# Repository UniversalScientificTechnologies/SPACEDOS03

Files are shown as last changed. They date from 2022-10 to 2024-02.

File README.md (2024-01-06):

# SPACEDOS03 - semiconductor-based ionizing radiation spectrometer



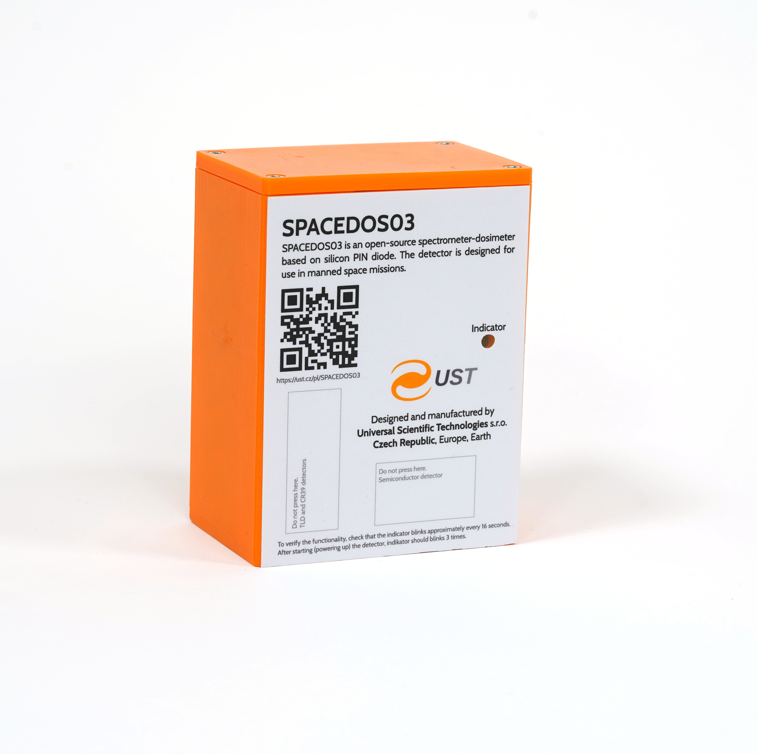
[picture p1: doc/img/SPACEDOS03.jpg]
SPACEDOS03A front panel


SPACEDOS03 is an open-source semiconductor particle detector (dosimeter and spectrometer) for space applications. The detector is based on a silicon PIN diode. The Detector is designed as autonomous for long-term measurement campaigns and therefore contains its power source from high-capacity battery cells and a recording medium in the form of an industrial SD card. The device is designed to be able to work for half a year continuously.

The detector is mounted into a 3D-printed box that contains positions for passive TLDs and track detectors. The main purpose of the device is experimental testing of radiation shielding materials in the real environment. 

## Parameters

 * Silicon PIN diode detector with 44 mm³ detection volume
 * Effective number of energy channels 470 ±3
 * Deposited energy ranges from 60 keV to 7 MeV
 * Energy measurement resolution 15 ±2 keV (depending on calibration method and type of particles)
 * Power supply 18650 Li-ion cells
 * Integration time depends on firmware setup 
 * Data storage device: Industrial SLC SDcard
 * Dimensions - 120 x 90 x 62 mm
 * Weight - 447 grams (with SAFT batteries)

* [Power module](https://github.com/ust-modules/UST5BATT18650V01)

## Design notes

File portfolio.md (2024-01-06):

---
title: "Radiation shielding materials tester"
excerpt: "SPACEDOS03 is a experimental dosimeter for testing of radiation shielding materials on board of manned spacecraft."
header:
  image: products/SPACEDOS03/doc/img/SPACEDOS03.jpg
  teaser: products/SPACEDOS03/doc/img/SPACEDOS03.jpg
  overlay_color: "#000"
  overlay_filter: "0.5"
  overlay_image: products/SPACEDOS02A/doc/src/img/SPACEDOS02A_bottom.jpg
---

SPACEDOS03A front panel

SPACEDOS03 is an open-source semiconductor particle detector (dosimeter and spectrometer) for space applications. The detector is based on a silicon PIN diode. The Detector is designed as autonomous for long-term measurement campaigns and therefore contains its own power source from high-capacity battery cells and a recording medium in the form of an industrial SD card. The device is designed to be able to work for half a year continuously.

The detector is mounted into a 3D-printed box that contains positions for passive TLDs and track detectors.

## Parameters

 * Silicon PIN diode detector with 44 mm³ detection volume
 * Effective number of energy channels 470 ±3
 * Deposited energy ranges from 60 keV to 7 MeV
 * Energy measurement resolution 15 ±2 keV (depending on calibration method and type of particles)
 * Power supply 18650 Li-ion cells
 * Integration time depends on firmware setup
 * Data storage device: Industrial SLC SDcard
 * Dimensions - 120 x 90 x 62 mm
 * Weight - 447 grams (with SAFT batteries)

The device is being used onboard ISS.

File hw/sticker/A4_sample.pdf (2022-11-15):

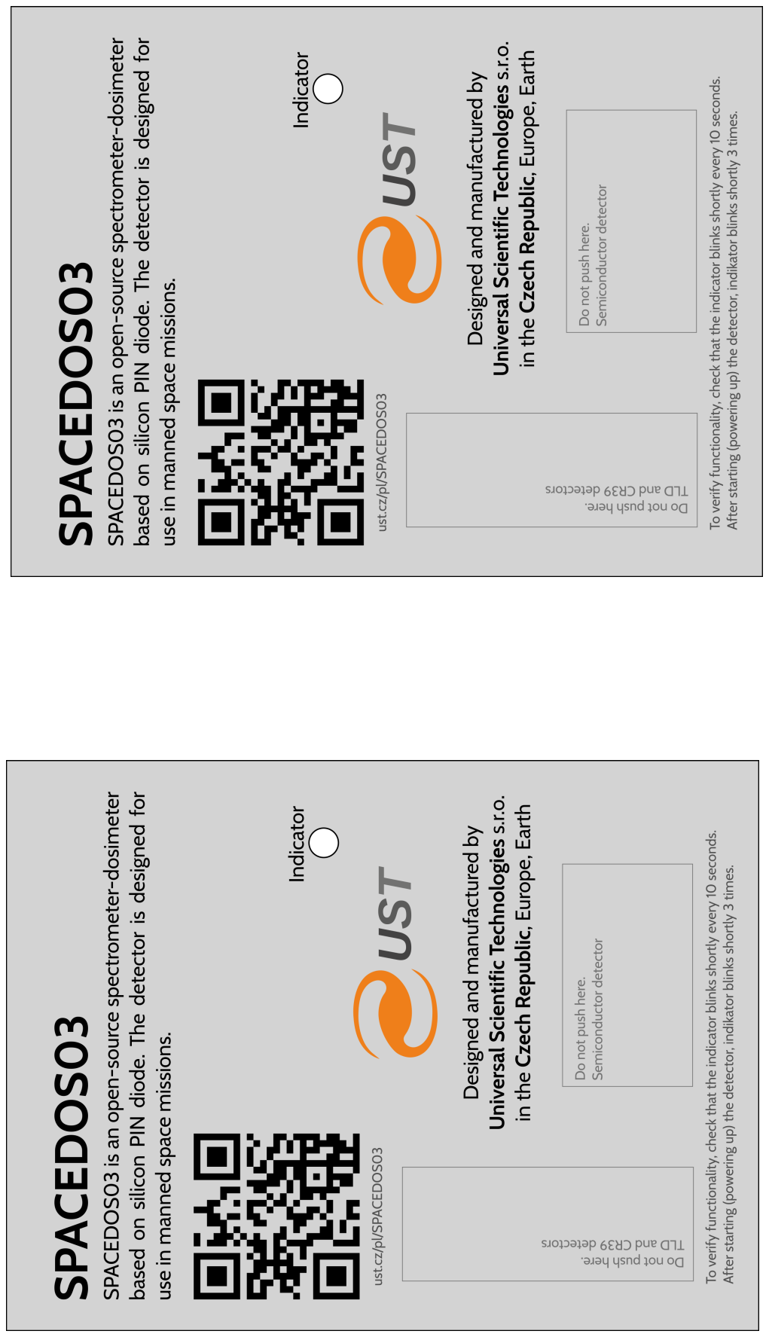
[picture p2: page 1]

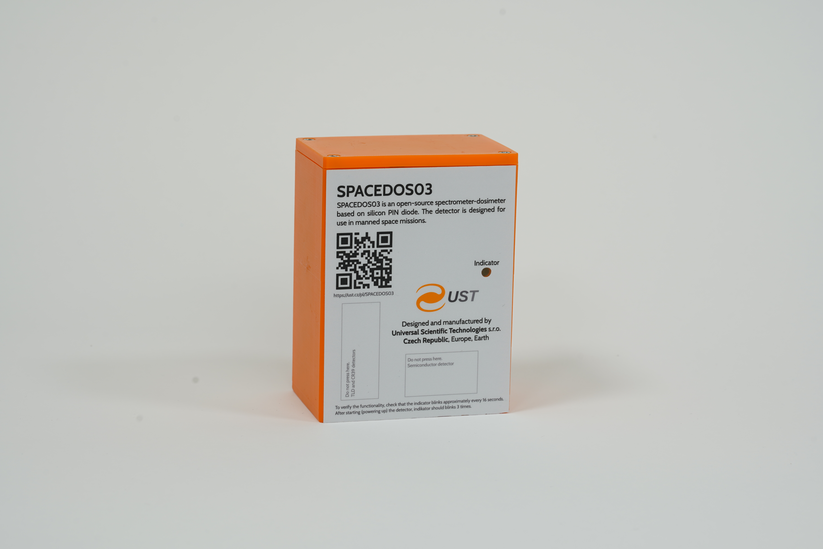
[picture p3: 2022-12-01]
doc/img/SPACEDOS03_front.jpg

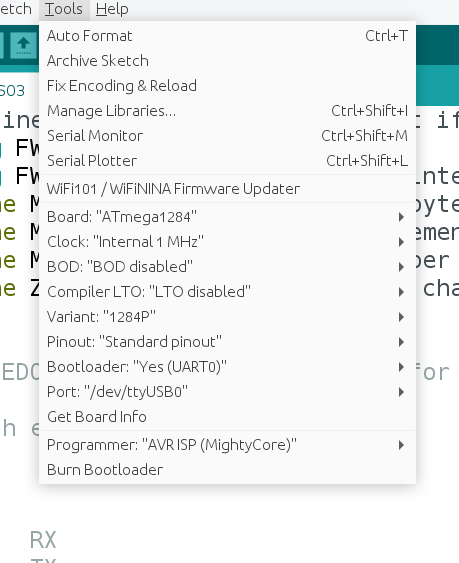
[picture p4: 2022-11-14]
fw/SPACEDOS03/compile_config.png

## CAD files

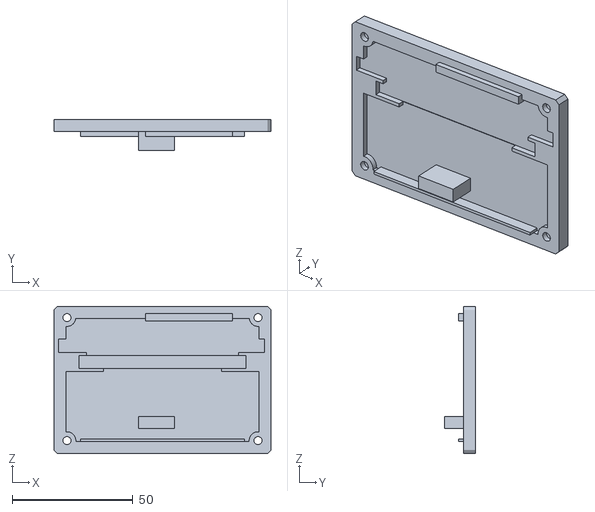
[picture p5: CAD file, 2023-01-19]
hw/stl/spacedos_cap.stl
90.0 x 12.7 x 61.0

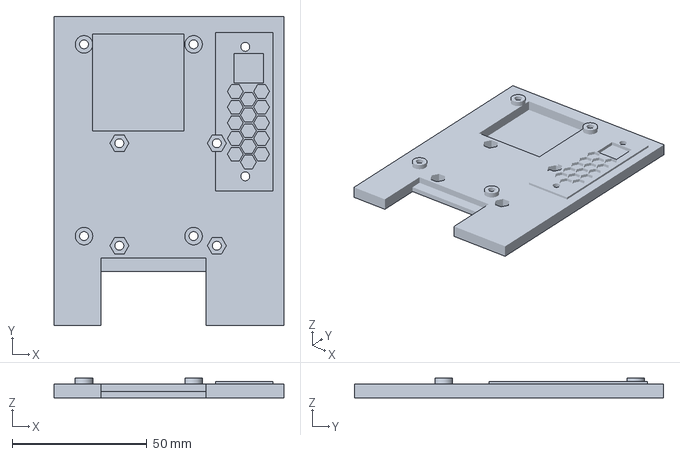
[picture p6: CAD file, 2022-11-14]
hw/stl/spacedos_desk.3mf
85.2 x 114.6 x 7.30 mm

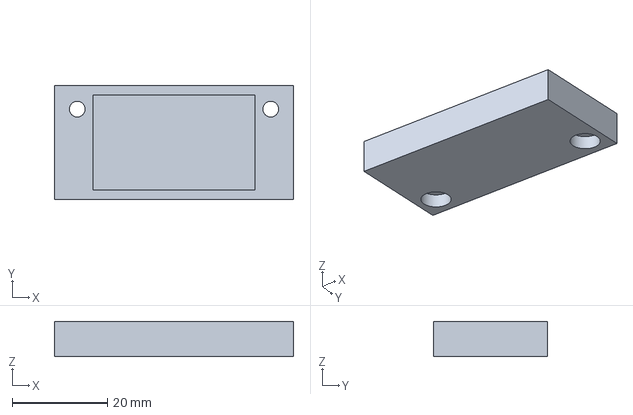
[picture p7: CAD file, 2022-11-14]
hw/stl/shield_pin.3mf
50.2 x 24.0 x 7.40 mm

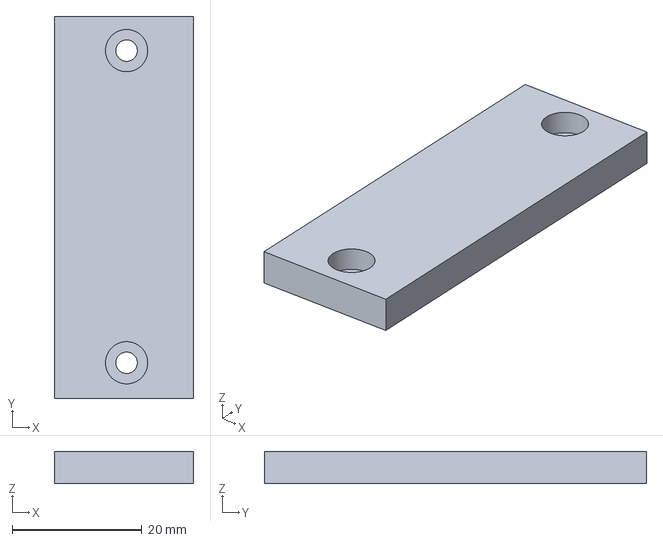
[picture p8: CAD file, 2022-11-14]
hw/stl/shield_tld.3mf
21.4 x 58.8 x 5.00 mm

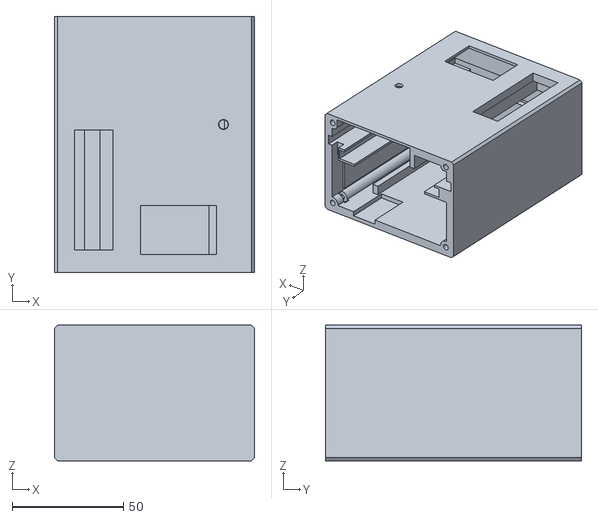
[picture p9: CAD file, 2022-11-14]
hw/stl/spacedos_box.stl
90.0 x 115.0 x 61.0

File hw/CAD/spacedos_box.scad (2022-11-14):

$fn=6;

repair=100;
repair_s=2;

toleration=0.4;// if zmena -> zmenit i u desky
//krabicka
thickness=5;

box_out_x=90;
box_out_y=120;
box_out_z=61;

box_in_x=box_out_x-2*thickness;
box_in_y=box_out_y-2*thickness;
box_in_z=box_out_z-2*thickness;

//nut
box_nut_d=6.78;
box_nut_h=3.3;
box_nut_d_x=-box_nut_d/2+box_out_x-2;
box_nut_d_x_2=box_nut_d/2+2;
box_nut_d_y=box_in_y;
box_nut_d_z=box_nut_d/2+2;
box_nut_d_z_2=box_nut_d/2+2+box_in_z;

box_nut_in_d=3.3;
box_nut_in_h=repair;
box_nut_in_repair=5;

box_nut_screw_d=6;
box_nut_screw_zapusteni=3;


//insertion
box_cor=thickness-2;
box_cor_d_xy=thickness-box_cor;
box_cor_d_z=box_cor_d_xy+36+4;
desk_z=5-1.5;//z ust_desk

//edge
edge_x=thickness-3;
edge_y=box_out_y+repair;
edge_z=repair;

//battery
bat_x=70;
bat_y=box_in_y-15;
bat_z=2+repair_s;

bat_x_trans=box_out_x/2-bat_x/2;
bat_y_trans=thickness-bat_y+box_in_y;
bat_z_trans=thickness-1.5;
/*
battery_d=33.5;
battery_h=80+(box_in_y-80)/2;//64.15
battery_in_h=32.12;
battery_distance=38/2;//19.17;
battery_zapusteni=1.5;
*/


//horni vyrez
h_v_x=46+5;
h_v_y=box_in_y;
h_v_z=1.45+2+repair_s;

h_v_x_trans=30.5;
h_v_y_trans=thickness;
h_v_z_trans=box_out_z-(thickness+repair_s);

//vystuha horni
v_h_x=3;
v_h_y=box_in_y;
v_h_z=box_in_z-box_cor_d_z+h_v_z-repair_s;

v_h_x_trans=h_v_x_trans-v_h_x;
v_h_y_trans=thickness;
v_h_z_trans=box_cor_d_z+desk_z+repair_s;

//vystuha bocni
v_b_x=box_in_x+repair_s;
v_b_y=box_in_y+repair_s;
v_b_z=v_h_x;

v_b_x_trans=-v_b_x/2+box_out_x/2;
v_b_y_trans=thickness-repair_s;
v_b_z_trans=box_out_z/3;

//vyrez vystuhy bocni
v_v_b_x=72;
v_v_b_y=box_in_y;
v_v_b_z=v_h_x+6;

v_v_b_x_trans=-v_v_b_x/2+box_out_x/2;
v_v_b_y_trans=thickness;
v_v_b_z_trans=box_out_z/3-6/2;

//vulcan
vulcan_diameter_1_out=7;
vulcan_diameter_2_out=8.5;

vulcan_diameter_1_in=3;
vulcan_diameter_2_in=4.5;
vulcan_height=1.5+thickness;

vulcan_trans_x=76;
vulcan_trans_y=thickness-box_cor+64.5;
vulcan_trans_z=box_cor_d_z+desk_z+repair_s+7;

//vnitrni opora
tloustka=1;
zapusteni=2;

//vnitrni horni opora vicka
v_o_v_x=36;
v_o_v_y=zapusteni+box_cor_d_xy;
v_o_v_z=tloustka+2;

v_o_v_x_trans=-v_o_v_x/2+h_v_x_trans+h_v_x/2;
v_o_v_y_trans=box_out_y-box_cor-v_o_v_y;
v_o_v_z_trans=box_out_z-thickness-tloustka;

//bocni vnitrni opora vicka +x
b_o_x_x=tloustka;
b_o_x_y=zapusteni+box_cor_d_xy;
b_o_x_z=10;

b_o_x_x_trans=thickness+box_in_x-b_o_x_x;
b_o_x_y_trans=box_out_y-box_cor-b_o_x_y;
b_o_x_z_trans=-b_o_x_z+box_cor_d_z;

//bocni vnitrni opora vicka -x
b_o__x_x=tloustka;
b_o__x_y=zapusteni+box_cor_d_xy;
b_o__x_z=10;

b_o__x_x_trans=thickness;
b_o__x_y_trans=box_out_y-box_cor-b_o_x_y;
b_o__x_z_trans=-b_o_x_z+box_cor_d_z;

//vnitrni dolni opora vicka
v_d_v_x=bat_x-repair_s;
v_d_v_y=zapusteni+box_cor_d_xy;
v_d_v_z=tloustka;

v_d_v_x_trans=-v_d_v_x/2+box_out_x/2;
v_d_v_y_trans=box_out_y-box_cor-v_o_v_y;
v_d_v_z_trans=thickness;

//rozmery diody
di_in_x=34;
di_in_y=22;
di_in_z=2.4;

//pomocne pro diodu z desk
nut_d=6.5;
box_cor_2=thickness-2;
k_x=26.41-box_cor_2-repair_s/2-1;
k_y=box_in_y+box_cor+repair_s-2*box_cor_2-2*repair_s;//box_in_x+2*box_cor-2*box_cor_2-2*repair_s;

k_y_trans=repair_s/2;

k_y_zkrat=(box_in_y+box_cor+repair_s-2*box_cor_2-2*repair_s)/2-nut_d+5;

k_x_trans=box_in_x+2*box_cor-3-k_x-box_cor_2-repair_s/2+3; //if zmena -> zmenit box

plate_s_x=34;//32.70
plate_x= 50.4;//box_in_x+2*box_cor;//

//kvadr pro krystaly
k_z=3-2;
k_v_z=5;//2;

//stinitko = stinici filtr (69x115x5)
stinitko_x = 69;
stinitko_y = 115;
stinitko_z = 5;

//stinitko tloustka uchyceni
stinitko_thick_z = 1.5;
stinitko_rezerva = 0.2;

//stinitko delka v uchaceni
stinitko_le_x = 10;

//baterie
baterie_x = 78.4;
baterie_y = 100.10+2.2;
baterie_z = 23.12+0.5;

//baterie spodni podlozeni
baterie_podl_distance= 55.5;
baterie_podl_x= 3.6;

//dratek
dratek=4.6;


vicko = 0; // zobrazit krabicku nebo vicko

difference(){
    cube([box_out_x, box_out_y, box_out_z]);
    difference(){
        translate([thickness, thickness, thickness]) cube([box_in_x, box_in_y+repair_s, box_in_z]);
        
        for(i=[box_nut_d_x, box_nut_d_x_2], j=[box_nut_d_z, box_nut_d_z_2])
        translate([i, 0, j]) translate([0, -box_nut_in_repair, 0])
            rotate([-90, 90,0]) cylinder(h=box_out_y+repair,d=box_nut_h+2*repair_s, $fn=100);
        
        //stinitko upevneni
        translate([thickness/2,thickness-box_cor,box_cor_d_z-stinitko_z-2*stinitko_thick_z]) cube([box_out_x, stinitko_y, stinitko_z+2*stinitko_thick_z]);
        
        //baterie
        translate([thickness/2, thickness, box_cor_d_z-stinitko_z-2*stinitko_thick_z-baterie_z]) cube([box_out_x, baterie_y, baterie_z]);
        
        //baterie spodni podlozeni
        for(i=[-baterie_podl_distance/2, baterie_podl_distance/2])translate([thickness+box_in_x/2-baterie_podl_x/2+i,thickness,0]) cube([baterie_podl_x,87,10+thickness]);
            
    
        }
   
    //insertion
    translate([box_cor_d_xy-toleration/2, box_cor_d_xy, box_cor_d_z])cube([box_in_x+2*box_cor-toleration, box_in_y+box_cor+repair_s, desk_z+repair_s]);
    
    //stinitko
    translate([-stinitko_x/2+box_out_x/2-stinitko_rezerva,thickness-box_cor-stinitko_rezerva,box_cor_d_z-stinitko_z-stinitko_thick_z-stinitko_rezerva]) cube([stinitko_x+2*stinitko_rezerva, stinitko_y+2*stinitko_rezerva, stinitko_z+2*stinitko_rezerva]);
    
    //stinitko zbaveni desek okolo
    translate([(-stinitko_x+2*stinitko_le_x+box_out_x)/2, thickness-box_cor,box_cor_d_z-stinitko_z-2*stinitko_thick_z])cube([stinitko_x-2*stinitko_le_x, stinitko_y, stinitko_z+2*(stinitko_thick_z)]);
     
    translate([(-stinitko_x+2*(stinitko_le_x-7)+box_out_x)/2, thickness-box_cor,box_cor_d_z-stinitko_z-2*stinitko_thick_z+stinitko_thick_z])cube([stinitko_x-2*(stinitko_le_x-7), stinitko_y, stinitko_z+2*(stinitko_thick_z)]);
    
//baterie
    translate([(-baterie_x+box_out_x)/2, thickness, box_cor_d_z-stinitko_z-2*stinitko_thick_z-baterie_z]) cube([baterie_x, baterie_y, baterie_z]);
    
    translate([55, 90, box_cor_d_z-stinitko_z-2*stinitko_thick_z-baterie_z-8]) cube([15, 25, 15]);
    
    //translate([thickness,thickness, box_cor_d_z-stinitko_z-2*stinitko_thick_z-baterie_z/2-baterie_z/4]) cube([box_in_x, baterie_y, baterie_z/2]);
        
    //dratek
        translate([box_out_x-thickness-dratek, box_out_y-thickness-dratek,box_cor_d_z-stinitko_z-2*stinitko_thick_z]) cube([dratek, dratek, stinitko_z+2*stinitko_thick_z]);    
        
    //screw
    for(i=[box_nut_d_x, box_nut_d_x_2], j=[box_nut_d_z, box_nut_d_z_2]){
        translate([i, box_nut_d_y, j]) 
            union(){
                translate([0, -box_nut_in_repair, 0]) rotate([-90, 90, 0])cylinder(h=box_nut_in_h, d=box_nut_in_d, $fn=100);
               translate([0, 2*thickness,0]) rotate([90,0,0]) cylinder(h=box_nut_screw_zapusteni, d=box_nut_screw_d, $fn=100);
            }
        }
        
     //nut
     hull(){
            translate([box_nut_d_x, box_nut_d_y, box_nut_d_z_2]) rotate([90, 30,0]) cylinder(h=box_nut_h, d=box_nut_d);
            translate([box_nut_d_x_2, box_nut_d_y, box_nut_d_z]) rotate([90, 30,0]) cylinder(h=box_nut_h, d=box_nut_d);      
      }
      
      hull(){
            translate([box_nut_d_x, box_nut_d_y, box_nut_d_z]) rotate([90, 30,0]) cylinder(h=box_nut_h, d=box_nut_d);
            translate([box_nut_d_x_2, box_nut_d_y, box_nut_d_z_2]) rotate([90, 30,0]) cylinder(h=box_nut_h, d=box_nut_d);      
      }
  
    //edge i,j,k
        translate([box_out_x/2,0, box_out_z/2]) for(i=[0:3]) rotate([0,i*90,0])
        translate([box_out_x/2,edge_y/2-repair_s,box_out_z/2]) rotate([0,-45,0]) cube([edge_x, edge_y, edge_z], center=true);  
      
    //cover
    if(vicko){
    translate([-repair_s,box_out_y-thickness,-repair_s]) cube([box_out_x+repair, thickness+repair, box_out_z+repair]);
    }else{
        translate([-repair_s,-thickness,-repair_s]) cube([box_out_x+repair, box_out_y, box_out_z+repair]);

    }
    
    
    
        
    
    //vulcan odecet
    translate([vulcan_trans_x, vulcan_trans_y, vulcan_trans_z]) cylinder(h=vulcan_height, d1=vulcan_diameter_1_in, d2=vulcan_diameter_2_in, $fn=100);
    
    //battery
    //translate([bat_x_trans, bat_y_trans, bat_z_trans]) cube([bat_x, bat_y, bat_z]);
 
    
    //vyrez pro diodu
    translate([(h_v_x_trans+h_v_x)/2-2,box_cor+repair_s+3,box_in_z+thickness])
        cube([di_in_x, di_in_y, di_in_z+2*repair_s]);
    //puvodni trans_x: box_out_x-0.3-(plate_x-plate_s_x)/2)-di_in_x

    //vyrez pro zasunuti krabicky na krystaly
   
    if(vicko) translate([thickness, thickness,box_cor_d_z+desk_z+repair_s]) cube([k_x,k_y+repair,k_z+k_v_z]);
    
    //vyrez pro krabicku na TLD
    translate([thickness+4,thickness+5,box_cor_d_z+desk_z+repair_s])cube([k_x-4, k_y-k_y_zkrat, k_z+k_v_z+repair]);

    //horni vyrez
    translate([h_v_x_trans,h_v_y_trans,h_v_z_trans]) cube([h_v_x, h_v_y, h_v_z]);
}  

if(vicko){
    //vystuha horni
    translate([v_h_x_trans, v_h_y_trans, v_h_z_trans]) cube([v_h_x, v_h_y,v_h_z]);
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

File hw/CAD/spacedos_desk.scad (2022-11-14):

$fn=100;

repair=100;
repair_s=2;
toleration=0.4;// if zmena -> zmenit i u boxu
//plate_s
//potreba pro plate_s z ust_box
thickness=5;

box_out_x=90;
box_out_y=120;
box_out_z=61;

box_in_x=box_out_x-2*thickness;
box_in_y=box_out_y-2*thickness;
box_in_z=box_out_z-2*thickness;

box_cor=thickness-2-toleration;

desk_z=5-toleration-1.5;//z ust_desk
////
plate_x= 50.4;//box_in_x+2*box_cor;//
plate_y=92.27;//box_in_y+box_cor+repair_s; //92.27;
plate_z= 4.34-1.5;//desk_z+repair_s;//

//vyrez na "krabicku"
plate_s_x=34;//32.70
plate_s_y=plate_s_x+2;
plate_s_z=6.32+1.3-0.5;

plate_s_z_trans=-0.5;
plate_s_distance=2.22-2/2;
plate_s_thickness=1;

//screw
nut_d_in=3.3;
nut_d_out=6.5;
spacedos_middle_x = 25;
nut_distance_x=spacedos_middle_x - 40.64/2;//1.87+nut_d_out/2;
nut_distance_y=-7+12;
nut_distance_y_2 = nut_distance_y+71.12;
nut_distance_x_2=spacedos_middle_x + 40.64/2;
nut_height=2.2+repair_s;//(plate_s_z+plate_s_thickness)-plate_z;

//nut
nut_d=6.5;
nut_h=3-plate_s_thickness;

//cut_out
c_c_x=35+4;
c_c_y=8;
c_c_z=5;//4.24
c_c_x_trans=-4/2;
c_c_distance_x=2+c_c_x_trans;
c_c_distance_y=plate_y-c_c_y;
c_c_distance_z=plate_s_thickness;
cube_i_y=5;

//translate_all
t_all_y=14;

///////////////////////////
//desk
desk_x=71.90;
desk_y=90.85;
//desk_z=5;//zapsano driv(20)
desk_overlap=3.3;

//nut
nut_diameter=7.05;//6.95;
nut_height_1=4+repair; //3.80
nut_d_x=15.15+desk_overlap+nut_diameter/2-0.77;
nut_d_x_2=(box_in_x+2*box_cor)/2+35.5/2-3;//desk_x+2*desk_overlap-15-nut_diameter/2;
nut_d_y=26.6;//23.01+nut_diameter/2;
nut_d_y_2=26.6+38;//64.69;//desk_y-23.35-nut_diameter/2;

box_nut_in_d=3.3;
box_nut_in_h=repair;

//correction (vycnelky spodni)
cor_diameter=2.97;
cor_d_x=2.09+desk_overlap;
cor_d_x_2=desk_x+2*desk_overlap-cor_d_x;
cor_d_y=26.19;
cor_d_y_2=desk_y-cor_d_y;
cor_height=3;

box_cor_2=thickness-2;

//kvadr pro krystaly
k_x=26.41-box_cor_2-repair_s/2-1;
k_y=box_in_y+box_cor+repair_s-2*box_cor_2-2*repair_s;//box_in_x+2*box_cor-2*box_cor_2-2*repair_s;
k_z=3-2;
k_y_zkrat=(box_in_y+box_cor+repair_s-2*box_cor_2-2*repair_s)/2-nut_d;

k_x_trans=box_in_x+2*box_cor-3-k_x-box_cor_2-repair_s/2+3; //if zmena -> zmenit box
k_y_trans=repair_s/2;
k_z_trans=desk_z+repair_s+(-desk_z-repair_s+plate_z+repair_s);

//kvadr pro krystaly vicko (x,y jako u kvadr pro krystaly)
k_v_z=5;//2;

//otvory pro krystaly
o_k_height=0.8+0.5;
o_k_diameter=4.7+0.75+((4.7+0.75)/2)*0.15425144988;
echo("prumer chlivecku, k opsana", o_k_diameter);
///////////////?
o_k_x_trans=k_x_trans+o_k_diameter;
o_k_y_trans=k_y_trans+k_y/2+((k_y-20)/4)/4;
o_k_z_trans=k_z+k_z_trans-o_k_height;

o_k_x_trans_posun=k_x;
o_k_y_trans_posun=(k_y-20)/8;
   
//koeficient pro posunuta vzdalenosti der pro krystaly
koeficient = 1.1;

//otvory pro krystaly 2.rada
o_k_x_2_trans=k_x_trans-o_k_diameter/2+k_x/2;//k_x_trans+k_x-2*o_k_diameter;
o_k_y_2_trans=k_y_trans+k_y/2;

//nut kvadr pro krystaly
nut_zapusteni=3+repair_s;
nut_zapusteni_trans_z=0;

//otvor pro krystal - cube
o_k_c=11;
o_k_c_height=1.5;

vicko=0;
//krystaly=1;
//tld_box = 1;

//plate
difference(){
    translate([-3,0,0]) union(){
       
        
        //vlozena deska
        //cube([plate_x, plate_y,plate_z+repair_s]);
       
        //velka deska
        translate([0,-3,-desk_z-repair_s+plate_z+repair_s])cube([box_in_x+2*box_cor, box_in_y+box_cor+repair_s, desk_z+repair_s]);
        
        //kvadr pro krystaly
        translate([k_x_trans, k_y_trans+k_y_zkrat, k_z_trans])
            cube([k_x, k_y-k_y_zkrat, k_z]);
        echo([k_x, k_y-k_y_zkrat, k_z]);
        
        
        //kvadr pro krystaly vicko
        translate([k_x_trans, k_y_trans+k_y_zkrat, k_z_trans+k_z+0.5]) cube([k_x, k_y-k_y_zkrat, k_v_z]);

       if(!vicko)
        //nuts_horni, $fn=100
        translate([plate_x+box_cor_2+3, plate_y+t_all_y, 0])rotate([0,0,180])
        for(i=[nut_distance_x, nut_distance_x_2], j=[nut_distance_y, nut_distance_y_2]){
        translate([i,j,plate_z]){
        difference(){
            cylinder(h=nut_height,d=nut_d_out);
            translate([0,0,-repair_s])cylinder(h=nut_height+repair,d=nut_d_in);
        }           
    }
}



        }
    
    
    translate([plate_x+box_cor_2, plate_y+t_all_y, plate_s_thickness])rotate([0,0,180]){
        
        //vyrez na "krabicku"
        translate([(plate_x-plate_s_x)/2, plate_s_distance, plate_s_z_trans]) cube([plate_s_x, plate_s_y, plate_s_z]);
       
       //vyrezy na konektory
        translate([c_c_distance_x, c_c_distance_y, c_c_distance_z]){            cube([c_c_x,c_c_y+repair,c_c_z+repair]);
        translate([0,cube_i_y,-desk_z-repair_s])
            cube([c_c_x,c_c_y+repair,c_c_z+repair]);
    }
   //nut_horni, $fn=6 + dira
    for(i=[nut_distance_x, nut_distance_x_2], j=[nut_distance_y, nut_distance_y_2]){
        translate([i,j,plate_z]){ translate([0,0,-plate_z-repair_s]) rotate([0,0,30]) cylinder(h=nut_h+repair_s, d=nut_d, $fn=6);
        translate([0,0,-4*repair_s])cylinder(h=nut_height+repair,d=nut_d_in);
        }
        }
    }
   translate([0,0,0]){ 
    //nut_spodni
    if(0){
       #for(i=[nut_d_x, nut_d_x_2 ], j=[nut_d_y, nut_d_y_2]){
        translate([i ,j, 1]) union(){
            cylinder(h=nut_height_1, d=nut_diameter, $fn=6);
            translate([0,0,-repair/2]) cylinder(h=box_nut_in_h, d=box_nut_in_d);
            }
        }
    }
        
    //vycnelky_spodni
    if(0) for(i=[cor_d_x, cor_d_x_2], j=[cor_d_y, cor_d_y_2]){
        translate([i, j, -repair_s])cylinder(h=cor_height, d=cor_diameter);
        }       
    }    
    
    translate([-5, -5, -5]) cube(10);
    
    translate([-1.5, 0, 0]){
    //otvor pro krystal - cube
    translate([2+o_k_x_2_trans-o_k_diameter,o_k_y_2_trans-o_k_diameter/2+6.3*o_k_diameter-0.4,o_k_z_trans+o_k_height-o_k_c_height])cube([o_k_c, o_k_c, o_k_c_height]);
    
    translate([1+0.5,k_y/5-0.4*o_k_diameter+0.3,0]){
     //otvory pro krystaly 1.rada
    for(i=[(-1/2*(o_k_y_trans_posun))*koeficient, 1/2 * (o_k_y_trans_posun)*koeficient, -(o_k_y_trans_posun)*koeficient, 0*(o_k_y_trans_posun*koeficient), o_k_y_trans_posun*koeficient]){
        translate([0,i,0]) translate([-o_k_diameter+o_k_x_2_trans+1, o_k_y_2_trans, o_k_z_trans]) cylinder(h=o_k_height, d=o_k_diameter, $fn=6);
    }
    
    //otvory pro krystaly 2.rada
    for(i=[(-1/2*(o_k_y_trans_posun))*koeficient, 1/2 * (o_k_y_trans_posun)*koeficient, -(o_k_y_trans_posun)*koeficient, 0*(o_k_y_trans_posun)*koeficient, o_k_y_trans_posun*koeficient]){
        translate([0,i,0]) translate([o_k_x_2_trans, o_k_y_2_trans-o_k_diameter/2, o_k_z_trans]) cylinder(h=o_k_height, d=o_k_diameter, $fn=6);
    }
     //otvory pro krystaly 3.rada
    for(i=[(-1/2*(o_k_y_trans_posun))*koeficient, 1/2 * (o_k_y_trans_posun)*koeficient, -(o_k_y_trans_posun)*koeficient, 0*(o_k_y_trans_posun)*koeficient, o_k_y_trans_posun*koeficient]){
        translate([0,i,0]) translate([o_k_diameter+o_k_x_2_trans-1, o_k_y_2_trans, o_k_z_trans]) cylinder(h=o_k_height, d=o_k_diameter, $fn=6);
    }
    
    }
}
    

    //nut kvadr pro krystaly    
    for(i=[nut_d+k_y_zkrat, k_y-nut_d/2-2.3]){
        echo("poloha sroubu", i);
        translate([k_x_trans+k_x/2-box_cor, i+0.8, -repair_s/7]){
    translate([0,0,0]) rotate([0,0,30]) cylinder(h=nut_h+repair_s, d=nut_d, $fn=6);
        translate([0,0,-4*repair_s])cylinder(h=nut_height+repair,d=nut_d_in);
        translate([0,0,k_z_trans+k_z+repair_s/7+repair_s]) cylinder(h=nut_zapusteni, d=nut_d, $fn=100);
        }
    }
    
       
   if(vicko){
    translate([-repair/2,-repair/2,-desk_z-repair+desk_z+repair_s+k_z]) cube([desk_x+repair, desk_y+repair, desk_z+repair]);
   }else{
        translate([k_x_trans-repair_s*4+1, k_y_trans+k_y_zkrat-1, k_z_trans+k_z]) cube([desk_x+repair, desk_y+repair, desk_z+repair]);
   }
}

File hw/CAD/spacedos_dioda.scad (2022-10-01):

$fn=100;

repair_s=2;
repair=100;

//sirka sroubu 
vzdalenost_sroubu=4*10.16; //jejich stredu

//rozmery diody
di_in_x=34;
di_in_y=20;
di_in_z=2.4;

//stinitko diody
di_out_x=50.2;
di_out_y=24;
di_out_z=di_in_z+5;

nut_d_y_2=26.6+38;
thickness=5;

box_out_y=120;
box_in_y=box_out_y-2*thickness;


//nut
nut_height=2.2+repair_s;//(plate_s_z+plate_s_thickness)-plate_z;
nut_d_in=3.3;
nut_d=6.5;


nut_trans_y=di_out_y/2-5;

nut_zapusteni=3+repair_s;


difference(){
    cube([di_out_x, di_out_y, di_out_z], center=true);
    #translate([0,0,-di_out_z/2+(di_in_z)/2]) cube([di_in_x, di_in_y, di_in_z], center =true);
    
   for(i=[vzdalenost_sroubu/2, -vzdalenost_sroubu/2]){ translate([i,nut_trans_y,-di_out_z-repair_s])cylinder(h=nut_height+repair,d=nut_d_in);
    translate([i,nut_trans_y,di_out_z/2-nut_zapusteni+repair_s]) cylinder(h=nut_zapusteni, d=nut_d, $fn=100);
    }
    
    
}

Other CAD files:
hw/stl/shield_pin.stl
hw/stl/shield_tld.stl
hw/stl/spacedos_desk.stl

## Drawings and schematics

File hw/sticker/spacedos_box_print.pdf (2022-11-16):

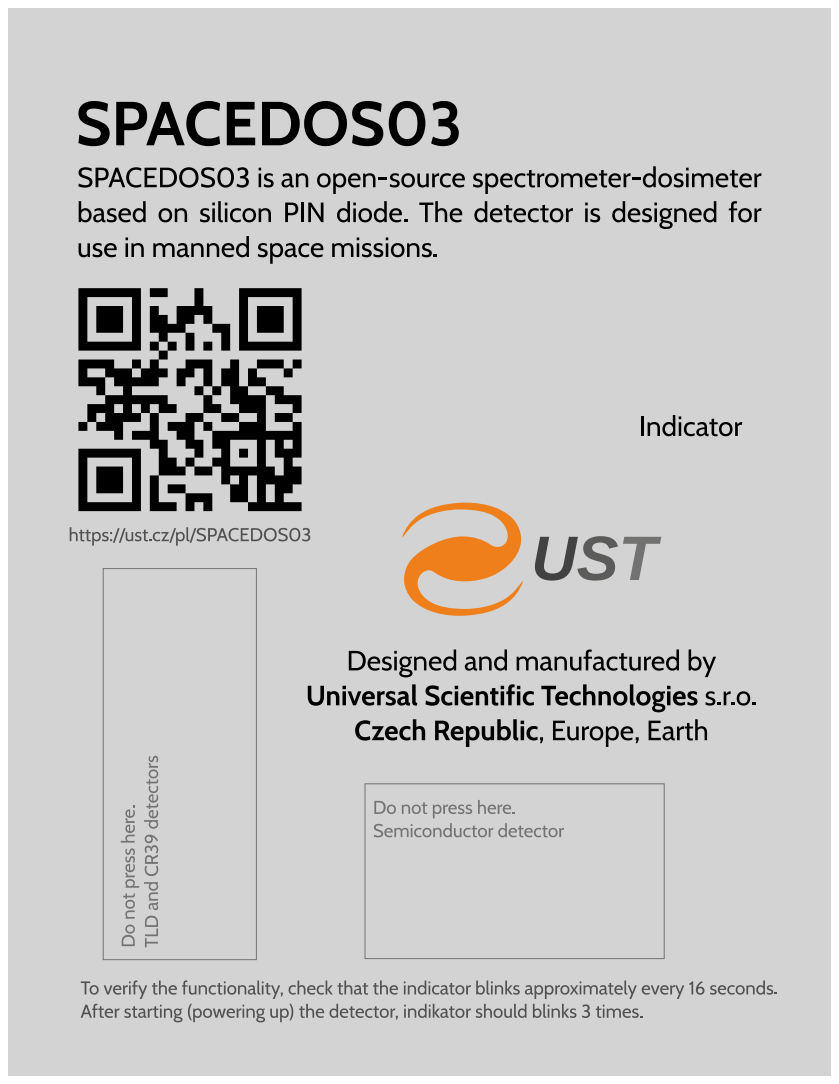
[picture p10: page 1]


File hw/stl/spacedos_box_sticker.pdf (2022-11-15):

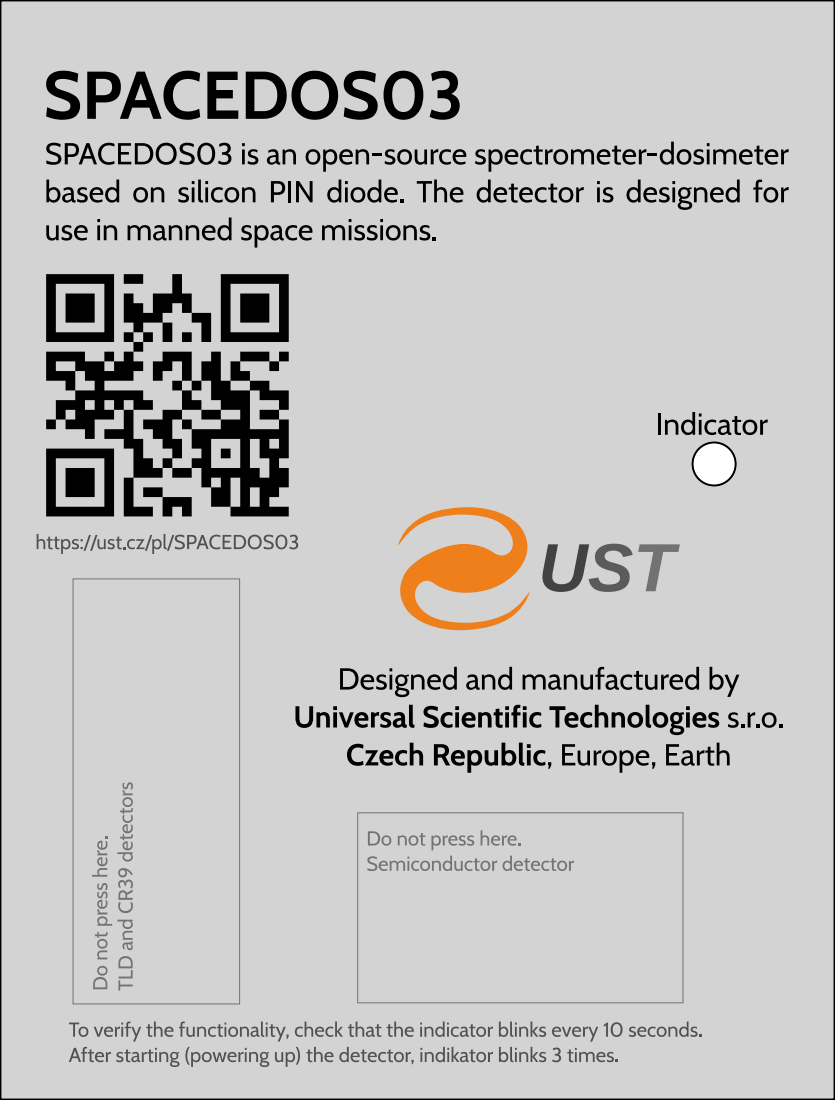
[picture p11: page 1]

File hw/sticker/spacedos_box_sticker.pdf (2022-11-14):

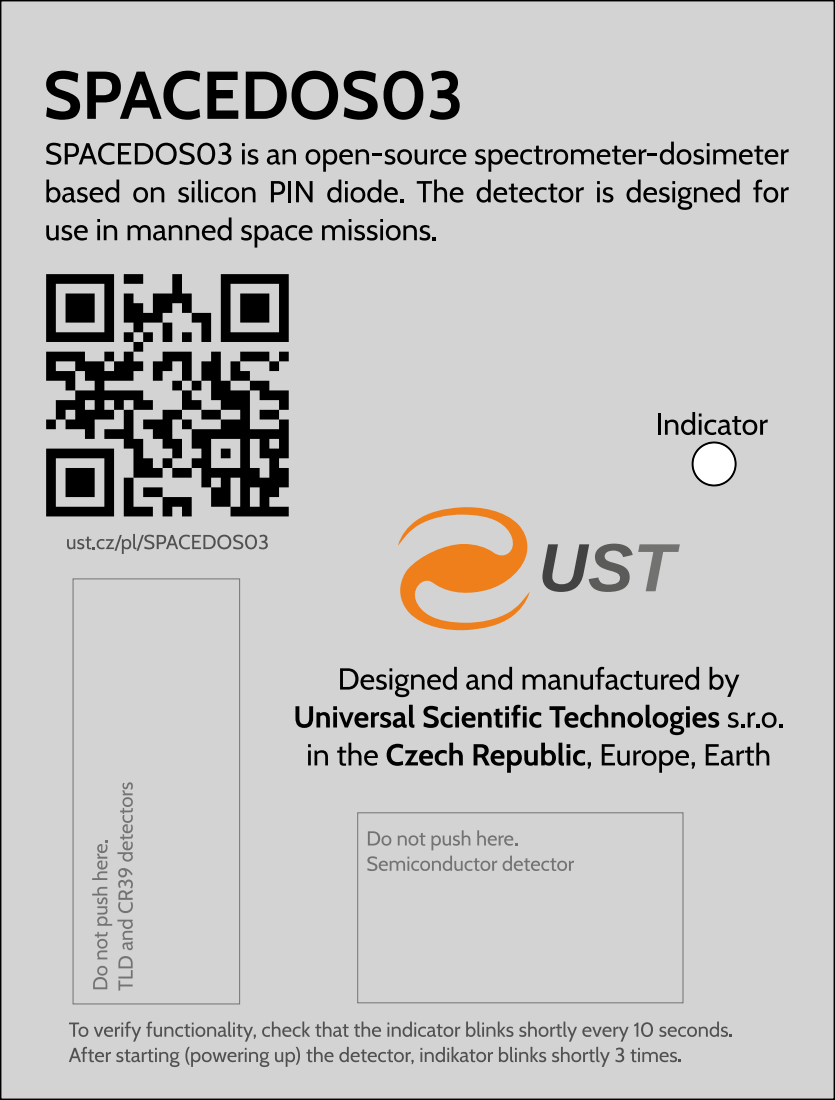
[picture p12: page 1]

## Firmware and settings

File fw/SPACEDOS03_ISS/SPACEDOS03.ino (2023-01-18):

//#define DEBUG // Please comment it if you are not debugging
// Compiled with: Arduino 1.8.13
// MightyCore 2.0.3
String HWtype = "SPACEDOS03";
String FWversion = "S04"; // 1 MHz internal oscillator / 500 kHz during integration 
#define MAXFILESIZE MAX_MEASUREMENTS * BYTES_MEASUREMENT // in bytes, 4 MB per day, 28 MB per week, 122 MB per month
#define MAX_MEASUREMENTS 11000ul // in measurement cycles, 5 500 per day
#define BYTES_MEASUREMENT 531ul // number of bytes per one measurement
#define MAXFILES 200 // maximal number of files on SD card
#define ZERO 256  // 5th channel is channel 1 (column 10 from 0, ussually DCoffset or DCoffset+1)

/*
  SPACEDOS03 derived from AIRDOS-F for USTSIPIN02A
 
6 month endurance with 5x LG 18650
https://batterybro.com/blogs/18650-wholesale-battery-reviews/40773059-new-lg-mj1-18650-battery-review-3500mah

ISP
---
PD0     RX
PD1     TX
RESET#  through 50M capacitor to RST#

SDcard
------
DAT3   SS   4 B4
CMD    MOSI 5 B5
DAT0   MISO 6 B6
CLK    SCK  7 B7

ANALOG
------
+      A0  PA0
-      A1  PA1
RESET  0   PB0

LED
---
LED_green  23  PC7      


                     Mighty 1284p    
                      +---\/---+
           (D 0) PB0 1|        |40 PA0 (AI 0 / D24)
           (D 1) PB1 2|        |39 PA1 (AI 1 / D25)
      INT2 (D 2) PB2 3|        |38 PA2 (AI 2 / D26)
       PWM (D 3) PB3 4|        |37 PA3 (AI 3 / D27)
    PWM/SS (D 4) PB4 5|        |36 PA4 (AI 4 / D28)
      MOSI (D 5) PB5 6|        |35 PA5 (AI 5 / D29)
  PWM/MISO (D 6) PB6 7|        |34 PA6 (AI 6 / D30)
   PWM/SCK (D 7) PB7 8|        |33 PA7 (AI 7 / D31)
                 RST 9|        |32 AREF
                VCC 10|        |31 GND
                GND 11|        |30 AVCC
              XTAL2 12|        |29 PC7 (D 23)
              XTAL1 13|        |28 PC6 (D 22)
      RX0 (D 8) PD0 14|        |27 PC5 (D 21) TDI
      TX0 (D 9) PD1 15|        |26 PC4 (D 20) TDO
RX1/INT0 (D 10) PD2 16|        |25 PC3 (D 19) TMS
TX1/INT1 (D 11) PD3 17|        |24 PC2 (D 18) TCK
     PWM (D 12) PD4 18|        |23 PC1 (D 17) SDA
     PWM (D 13) PD5 19|        |22 PC0 (D 16) SCL
     PWM (D 14) PD6 20|        |21 PD7 (D 15) PWM
                      +--------+
*/

#include <SD.h>         
#include "wiring_private.h"
#include <Wire.h>   

#define LED         23   // PC7
#define RESET       0    // PB0
#define SDpower1    1    // PB1
#define SDpower2    2    // PB2
#define SDpower3    3    // PB3
#define SS          4    // PB4
#define MOSI        5    // PB5
#define MISO        6    // PB6
#define SCK         7    // PB7
#define INT         20   // PC4
#define ANALOG_ON   15   // PD7
#define LED1        21   // PC5
#define LED2        22   // PC6
#define LED3        23   // PC7

#define CHANNELS 512 // number of channels in buffer for histogram, including negative numbers

String filename = "";
uint16_t fn;
uint32_t count = 0;
uint32_t serialhash = 0;
uint16_t base_offset = ZERO - 1;
uint8_t lo, hi;
uint16_t u_sensor;

// Read Analog Differential without gain (read datashet of ATMega1280 for refference)
// Use analogReadDiff(NUM)
//   NUM  | POS PIN             | NEG PIN           |   GAIN
//  0 | A0      | A1      | 1x
//  1 | A1      | A1      | 1x
//  2 | A2      | A1      | 1x
//  3 | A3      | A1      | 1x
//  4 | A4      | A1      | 1x
//  5 | A5      | A1      | 1x
//  6 | A6      | A1      | 1x
//  7 | A7      | A1      | 1x
//  8 | A8      | A9      | 1x
//  9 | A9      | A9      | 1x
//  10  | A10     | A9      | 1x
//  11  | A11     | A9      | 1x
//  12  | A12     | A9      | 1x
//  13  | A13     | A9      | 1x
//  14  | A14     | A9      | 1x
//  15  | A15     | A9      | 1x
#define PIN 0
uint8_t analog_reference = INTERNAL2V56; // DEFAULT, INTERNAL, INTERNAL1V1, INTERNAL2V56, or EXTERNAL
// the differential channels should not be used with an AREF < 2V

uint32_t tm;

uint8_t bcdToDec(uint8_t b)
{
  return ( ((b >> 4)*10) + (b%16) );
}

void readRTC()
{
  Wire.beginTransmission(0x51);
  Wire.write(0);
  Wire.endTransmission();
  
  Wire.requestFrom(0x51, 6);
  Wire.read();
  //tm_s100 = bcdToDec(Wire.read());
  uint8_t tm_sec = bcdToDec(Wire.read() & 0x7f);
  uint8_t tm_min = bcdToDec(Wire.read() & 0x7f);
  tm = bcdToDec(Wire.read());
  tm += bcdToDec(Wire.read()) * 100;
  tm += bcdToDec(Wire.read()) * 10000;
  tm = tm * 60 * 60 + tm_min * 60 + tm_sec;
}

void(* resetFunc) (void) = 0; //declare reset function at address 0

void setup()
{
  // Open serial communications 
  enablePower(POWER_SERIAL0);
  interrupts();
  Serial.begin(9600);
  for(int i=0; i<3; i++)  
  {
    delay(300);
    digitalWrite(LED, HIGH);  // Blink indicating inserting batteryes (or reset)
    delay(10);
    digitalWrite(LED, LOW);  
  }
  Serial.println("#Cvak...");
  
  ADMUX = (analog_reference << 6) | ((PIN | 0x10) & 0x1F);
  
  ADCSRB = 0;               // Switching ADC to Free Running mode
  sbi(ADCSRA, ADATE);       // ADC autotrigger enable (mandatory for free running mode)
  sbi(ADCSRA, ADSC);        // ADC start the first conversions
  sbi(ADCSRA, 2);           // 0x100 = clock divided by 16, 62.5 kHz, 208 us for 13 cycles of one AD conversion, 24 us fo 1.5 cycle for sample-hold
  cbi(ADCSRA, 1);        
  cbi(ADCSRA, 0);        

  //pinMode(SDpower1, OUTPUT);  // SDcard interface
  //pinMode(SDpower2, OUTPUT);     
  //pinMode(SDpower3, OUTPUT);     
  //pinMode(SS, OUTPUT);     
  //pinMode(MOSI, INPUT);     
  //pinMode(MISO, INPUT);     
  //pinMode(SCK, OUTPUT);  

  DDRB = 0b10011110;
  PORTB = 0b00000000;  // SDcard Power OFF
  DDRA = 0b11111100;
  PORTA = 0b00000000;  
  DDRC = 0b11101100;
  PORTC = 0b00000000;  
  DDRD = 0b11111111;  
  PORTD = 0b10000000; // Analog Power ON 
  

  //!!! Wire.setClock(100000);
  // Initiation of RTC
  Wire.beginTransmission(0x51); // init clock
  Wire.write((uint8_t)0x23); // Start register
  Wire.write((uint8_t)0x00); // 0x23
  Wire.write((uint8_t)0x00); // 0x24 Two's complement offset value
  Wire.write((uint8_t)0b00000101); // 0x25 Normal offset correction, disable low-jitter mode, set load caps to 6 pF
  Wire.write((uint8_t)0x00); // 0x26 Battery switch reg, same as after a reset
  Wire.write((uint8_t)0x00); // 0x27 Enable CLK pin, using bits set in reg 0x28
  Wire.write((uint8_t)0x97); // 0x28 stop watch mode, no periodic interrupts, CLK pin off
  Wire.write((uint8_t)0x00); // 0x29
  Wire.write((uint8_t)0x00); // 0x2a
  Wire.endTransmission();
/*
  Wire.beginTransmission(0x51); // reset clock
  Wire.write(0x2f); 
  Wire.write(0x2c);
  Wire.endTransmission();
  Wire.beginTransmission(0x51); // start stop-watch
  Wire.write(0x28); 
  Wire.write(0x97);
  Wire.endTransmission();
  Wire.beginTransmission(0x51); // reset stop-watch
  Wire.write((uint8_t)0x00); // Start register
  Wire.write((uint8_t)0x00); // 0x00
  Wire.write((uint8_t)0x00); // 0x01 
  Wire.write((uint8_t)0x00); // 0x02 
  Wire.write((uint8_t)0x00); // 0x03
  Wire.write((uint8_t)0x00); // 0x04
  Wire.write((uint8_t)0x00); // 0x05
  Wire.endTransmission();
*/

  {
    // measurement of ADC offset
    ADMUX = (analog_reference << 6) | 0b10001; // Select +A1,-A1 for offset correction
    ADCSRB = 0;               // Switching ADC to Free Running mode
    sbi(ADCSRA, ADATE);       // ADC autotrigger enable (mandatory for free running mode)
    sbi(ADCSRA, ADSC);        // ADC start the first conversions
    sbi(ADCSRA, 2);           // 0x100 = clock 1 MHz divided by 16, 62.5 kHz, 208 us for 13 cycles of one AD conversion, 24 us fo 1.5 cycle for sample-hold
    cbi(ADCSRA, 1);
    cbi(ADCSRA, 0);
    sbi(ADCSRA, ADIF);                  // reset interrupt flag from ADC
    while (bit_is_clear(ADCSRA, ADIF)); // wait for the first conversion
    sbi(ADCSRA, ADIF);                  // reset interrupt flag from ADC
    lo = ADCL;
    hi = ADCH;
    delayMicroseconds(16); // 24 us wait for 1.5 cycle of 62.5 kHz ADC clock for sample/hold for next conversion     
    DDRB = 0b10011111;     // Reset peak detector
    delayMicroseconds(7);  // cca 7 us is neaded for 2k2 resistor and 100n capacitor in peak detector              
    DDRB = 0b10011110;

    uint16_t DCoffset;
    for (uint8_t n=0; n<8; n++) 
    { 
      while (bit_is_clear(ADCSRA, ADIF)); // wait for the first conversion
      sbi(ADCSRA, ADIF);                  // reset interrupt flag from ADC
      lo = ADCL;
      hi = ADCH;
      delayMicroseconds(16); // 24 us wait for 1.5 cycle of 62.5 kHz ADC clock for sample/hold for next conversion     
      DDRB = 0b10011111;     // Reset peak detector
      delayMicroseconds(7);  // cca 7 us is neaded for 2k2 resistor and 100n capacitor in peak detector              
      DDRB = 0b10011110;
      
      // combine the two bytes
      u_sensor = (hi << 7) | (lo >> 1);
      // manage negative values
      if (u_sensor <= (CHANNELS / 2) - 1 ) {
        u_sensor += (CHANNELS / 2);
      } else {
        u_sensor -= (CHANNELS / 2);
      }
      DCoffset += u_sensor;
    }
    base_offset = DCoffset >> 3; // Calculate mean of 8 measurements

    ADMUX = (analog_reference << 6) | 0b10000; // Select +A0,-A1 for measurement
    ADCSRB = 0;               // Switching ADC to Free Running mode
    sbi(ADCSRA, ADATE);       // ADC autotrigger enable (mandatory for free running mode)
    sbi(ADCSRA, ADSC);        // ADC start the first conversions
    sbi(ADCSRA, 2);           // 0x100 = clock divided by 16, 62.5 kHz, 208 us for 13 cycles of one AD conversion, 24 us fo 1.5 cycle for sample-hold
    cbi(ADCSRA, 1);
    cbi(ADCSRA, 0);

  }
    
  readRTC();
  Serial.println("#Hmmm...");

  // make a string for device identification output
  String dataString = "$DOS," + HWtype + "," + FWversion + "," + String(tm) + "," + String(base_offset) + ","; // log FW type and version 
  
  Wire.beginTransmission(0x58);                   // request SN from EEPROM
  Wire.write((int)0x08); // MSB
  Wire.write((int)0x00); // LSB
  Wire.endTransmission();
  Wire.requestFrom((uint8_t)0x58, (uint8_t)16);    
  for (int8_t reg=0; reg<16; reg++)
  { 
    uint8_t serialbyte = Wire.read(); // receive a byte
    if (serialbyte<0x10) dataString += "0";
    dataString += String(serialbyte,HEX);    
    serialhash += serialbyte;
  }

  {
    DDRB = 0b10111110;
    PORTB = 0b00001111;  // SDcard Power ON
  
    // make sure that the default chip select pin is set to output
    // see if the card is present and can be initialized:
    if (!SD.begin(SS)) 
    {
      Serial.println("#Card failed, or not present");
      DDRB = 0b10011110;
      PORTB = 0b00000001;  // SDcard Power OFF  
      delay(100);
      clock_prescale_set(clock_div_32); // CPU clock 250 kHz 
      delay(4000);      // 16 s
      clock_prescale_set(clock_div_8); // CPU clock 1 MHz 
      // don't do anything more:
      resetFunc();
    }
    
    for (fn = 1; fn<MAXFILES; fn++) // find last file
    {
       filename = String(fn) + ".txt";
       if (SD.exists(filename) == 0) break;
    }
    fn--;
    filename = String(fn) + ".txt";
    
    // open the file. note that only one file can be open at a time,
    // so you have to close this one before opening another.
    File dataFile = SD.open(filename, FILE_WRITE);

    uint32_t filesize = dataFile.size();
#ifdef DEBUG
    Serial.print("Filesize ");
    Serial.println(filesize); 
#endif
    if (filesize > MAXFILESIZE)
    {
      dataFile.close();
      fn++;
      filename = String(fn) + ".txt";      
      dataFile = SD.open(filename, FILE_WRITE);
    }
#ifdef DEBUG
    Serial.print("Filename ");
    Serial.println(filename); 
#endif
  
    // if the file is available, write to it:
    if (dataFile) 
    {
      dataFile.println(dataString);  // write to SDcard (800 ms)     
      dataFile.close();
  
      Serial.println(dataString);  // print SN to terminal 
    }  
    // if the file isn't open, pop up an error:
    else 
    {
      Serial.println("#error opening datalog.txt");
    }
  
    DDRB = 0b10011110;
    PORTB = 0b00000001;  // SDcard Power OFF          
  }  
  disablePower(POWER_TIMER1);
  disablePower(POWER_TIMER2);
  disablePower(POWER_TIMER3);
  disablePower(POWER_SERIAL1);
}

bool everithingOK = false;

void loop()
{
  PORTD = 0b10000000; // Analog Power ON 
  delay(100);

  uint16_t histogram[CHANNELS];  
  for(int n=0; n<CHANNELS; n++)
  {
    histogram[n]=0;
  }
    
  if (everithingOK)
  {
    digitalWrite(LED, HIGH);  // Blink on Lembit's demand
    Serial.println(count); 
    delay(10);     
    digitalWrite(LED, LOW);  
    everithingOK = false;        
  }
  // dosimeter integration
  uint16_t suppress = 0;      
  noInterrupts();
  cbi(ADCSRA, 2); // 0x011 = clock 500 kHz divided by 8, 62.5 kHz, 224 us for 14 cycles of one AD conversion
  sbi(ADCSRA, 1); // 4.5 kS/s, 24 us fo 1.5 cycle for sample-hold
  sbi(ADCSRA, 0); // successive approximation circuitry requires an input clock frequency between 50 kHz and 200 kHz
  sbi(ADCSRA, ADIF);                  // reset interrupt flag from ADC
  DDRB = 0b10011111;                  // Reset peak detector
  delayMicroseconds(50);              // Guarantead reset
  DDRB = 0b10011110;
  clock_prescale_set(clock_div_16); // CPU clock 500 kHz
  uint8_t previous_pulse = 1; // ignore the first ADC
  for (uint16_t i=65535; i>0; i--)    // 14.67984 s
  {
    while (bit_is_clear(ADCSRA, ADIF)); // wait for end of conversion 
    uint8_t missed_pulse = PINB; // peak of pulse was before S/H?
    //delayMicroseconds();              // 24 us wait for 1.5 cycle of 62.5 kHz ADC clock for sample/hold for next conversion
    sbi(ADCSRA, ADIF);                  // reset ADC interrupt flag
    asm("NOP");                                    // cca 30 us after conversion
    asm("NOP");
    asm("NOP");
    asm("NOP");
    asm("NOP");
    asm("NOP");
    asm("NOP");
    
    DDRB = 0b10011111;                  // Reset peak detector
    asm("NOP");                         // cca 7 us is neaded for 2k2 resistor and 100n capacitor in peak detector
    asm("NOP"); // 2 us for one NOP with 500 kHz CPU clock
    asm("NOP");
    DDRB = 0b10011110;

    // we have to read ADCL first; doing so locks both ADCL
    // and ADCH until ADCH is read.  reading ADCL second would
    // cause the results of each conversion to be discarded,
    // as ADCL and ADCH would be locked when it completed.
    lo = ADCL;
    hi = ADCH;

    // combine the two bytes
    u_sensor = (hi << 7) | (lo >> 1);

    // manage negative values
    if (u_sensor <= (CHANNELS/2)-1 ) {u_sensor += (CHANNELS/2);} else {u_sensor -= (CHANNELS/2);}
            
    if (previous_pulse & 1) 
    {
      suppress++;
    }
    else
    {
      histogram[u_sensor]++;
    }

    previous_pulse = missed_pulse;
  }  
  clock_prescale_set(clock_div_8); // CPU clock 1 MHz
  interrupts();
  PORTD = 0b00000000; // Analog Power OFF 
   
  // Data out
  {
    readRTC();

    // make a string for assembling the data to log:
    String dataString = "";

    #define RANGE 250
    
    // make a string for assembling the data to log:
    dataString += "$HIST,";
    dataString += String(count); 
    dataString += ",";  
    dataString += String(tm); 
    dataString += ",";
    dataString += String(suppress);
    
    for(int n=base_offset-1; n<(base_offset-1+RANGE); n++)  
    {
      dataString += ",";
      dataString += String(histogram[n]); 
    }

    count++;

    {
      DDRB = 0b10111110;
      PORTB = 0b00001111;  // SDcard Power ON

#ifdef DEBUG
      readRTC();
      Serial.print("SDwrite ");
      Serial.println(tm); 
#endif

      // make sure that the default chip select pin is set to output
      // see if the card is present and can be initialized:
      if (!SD.begin(SS)) 
      {
        // don't do anything more:
        resetFunc();
      }

      // open the file. note that only one file can be open at a time,
      // so you have to close this one before opening another.
      File dataFile = SD.open(filename, FILE_WRITE);
    
      // if the file is available, write to it:
      if (dataFile) 
      {
        dataFile.println(dataString);  // write to SDcard (800 ms) 
        dataFile.close();
        everithingOK = true;
      }  
      else
      {
        resetFunc();
      }

#ifdef DEBUG
      readRTC();
      Serial.print("SDwrite ");
      Serial.println(tm); 
#endif

      DDRB = 0b10011110;
      PORTB = 0b00000001;  // SDcard Power OFF

#ifdef DEBUG
      Serial.println(dataString);  // print to terminal (additional 700 ms in DEBUG mode)
      delay(100);
#endif

      if (count > MAX_MEASUREMENTS) 
      {
        count = 0;
        fn++;
        filename = String(fn) + ".txt";        
#ifdef DEBUG
      Serial.println(filename); 
#endif
      }
    }          
  }    
}

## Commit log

2022-09-29 shielding parts, stl
    [shield_pin.stl, shield_tld.stl]
2022-10-01 render STL files
    [spacedos_box.scad, spacedos_box.stl, spacedos_desk.scad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]
2022-10-03 shield material
    [shield_tld.stl]
2022-10-05 Model update, add 3mf
    [shield_pin.3mf, shield_tld.3mf, spacedos_desk.scad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]
2022-10-06 add desk file
    [spacedos_desk.3mf]
2022-11-09 new version of box
    [spacedos_box.scad, spacedos_box.stl]
2022-11-13 Last version of box
    [spacedos_box.scad, spacedos_desk.scad, spacedos_desk.stl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]
2022-11-13 battery endurance calculation
2023-01-18 Update arduino-board-fqbn value.
2023-01-19 Rename STL.
    [spacedos_cap.stl]
2023-01-19 Rendering the STL.
    [spacedos_cap.stl]
2023-09-01 Update README.md
    Correct the PIN diode detection volume.
